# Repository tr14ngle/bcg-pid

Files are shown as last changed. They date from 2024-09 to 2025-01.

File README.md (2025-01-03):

# Digitally tuned analog PID controller for BCG system

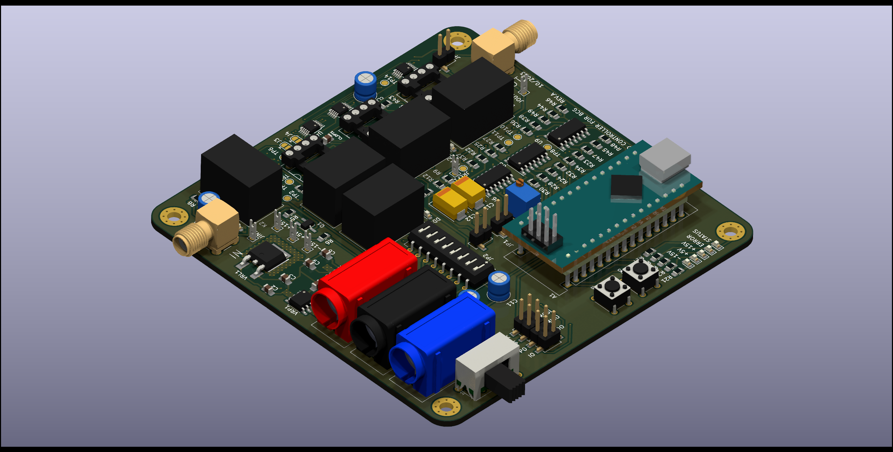
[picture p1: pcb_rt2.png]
PID Controller


## Overview

This repository contains KiCad files, as well as some LTSpice simulations for an experimental digitally tuned PID controller. The controller is designed to be part of a ballistocardiography (BCG) measuring system. In BCG, the function of the heart is measured by th forces caused by movement of the blood as a result of heartbeat. This is in contrast to better known electrocardiography (ECG), where heart function is assessed by measuring electrical signals. Compared to ECG, where the shape of the waveform is more important, in BCG the amplitude of the BCG signal carries important information about the heart's condition. Because BCG measures physical force, the patient's mass, among other things, can influence the amplitude of the signal. This makes long-term measurements difficult because the patient's weight and other affecting factors often vary over time. 

This PID controller is a continuation of a project completed Aalto University's Automation and Electrical Engineering Master Programme's Project Work course ([link to project folder](https://wiki.aalto.fi/display/AEEproject/Instrumentation+for+Ballistocardiography+2023?searchId=NLV66OIGJ)). Over the course, a system was implemented where the patient lays on suspended frame. The motion of the suspended frame can be controlled using two solenoids. A load cell is used to measure the position of the frame and a PID controller then controls the solenoids in such a way that the bed frame is kept stationary. This way, when the patient lays motionless, the BCG signal can be aquired from the control signals of the solenoids. This approach keeps the patient's body stationary, effectively canceling body inertia, which normalizes the resultant BCG signal. During the course, an unconventional, analogic PID controller was implemented. The controller was manually tuned using potentiometer which proved unfeasible, as manual tuning was quite diffictult and necessary for each measurement. This project attempts to address this by implementing digital tuning of the P, I and D blocks using digital potentiometers.

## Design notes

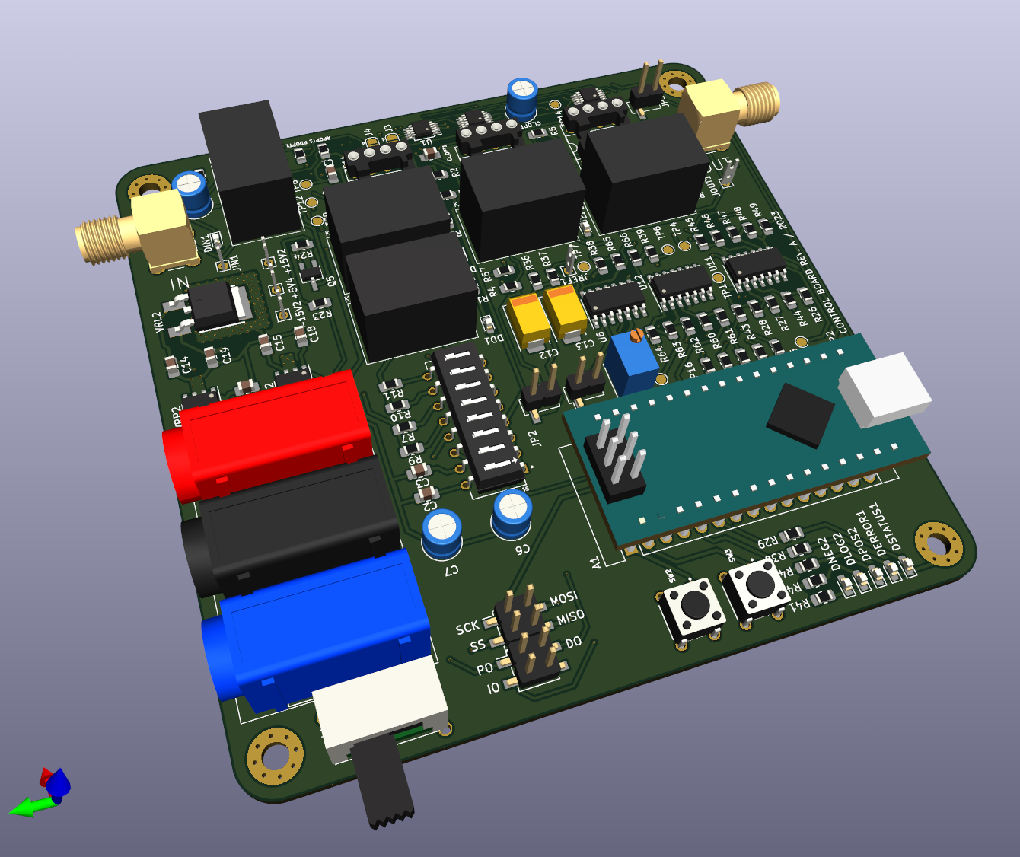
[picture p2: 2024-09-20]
pcb3.png

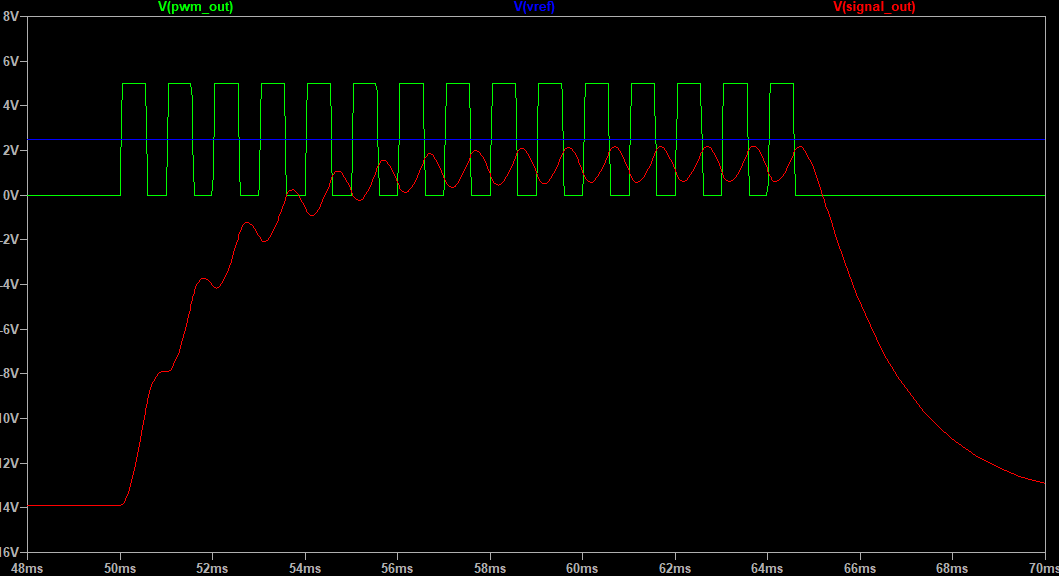
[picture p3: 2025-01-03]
bcg_spice/out_signals.PNG

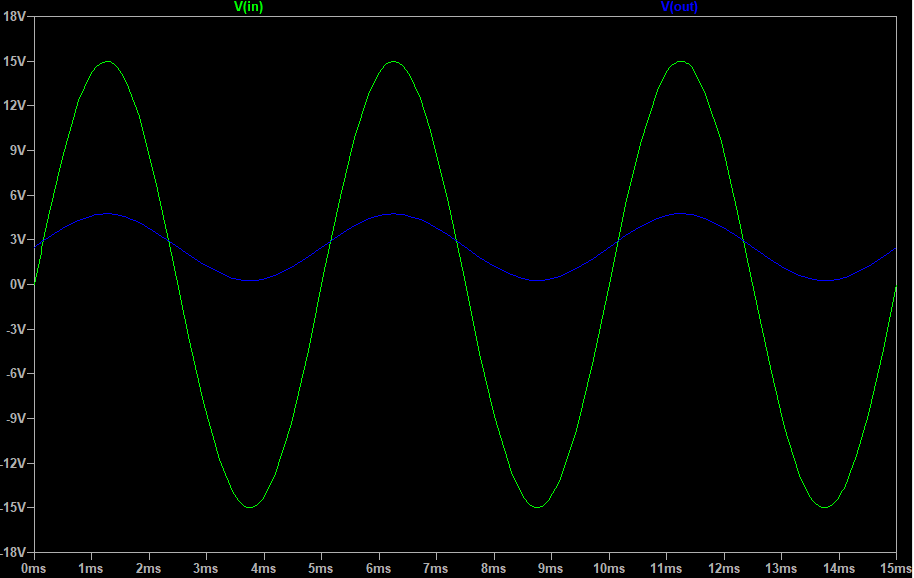
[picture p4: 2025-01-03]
bcg_spice/in_signals.PNG

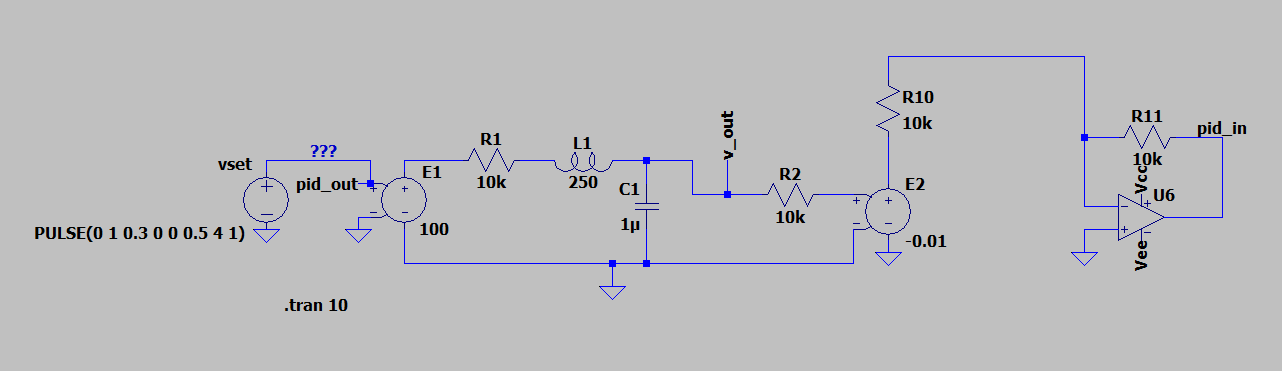
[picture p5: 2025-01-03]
bcg_spice/pid_dynamics.PNG

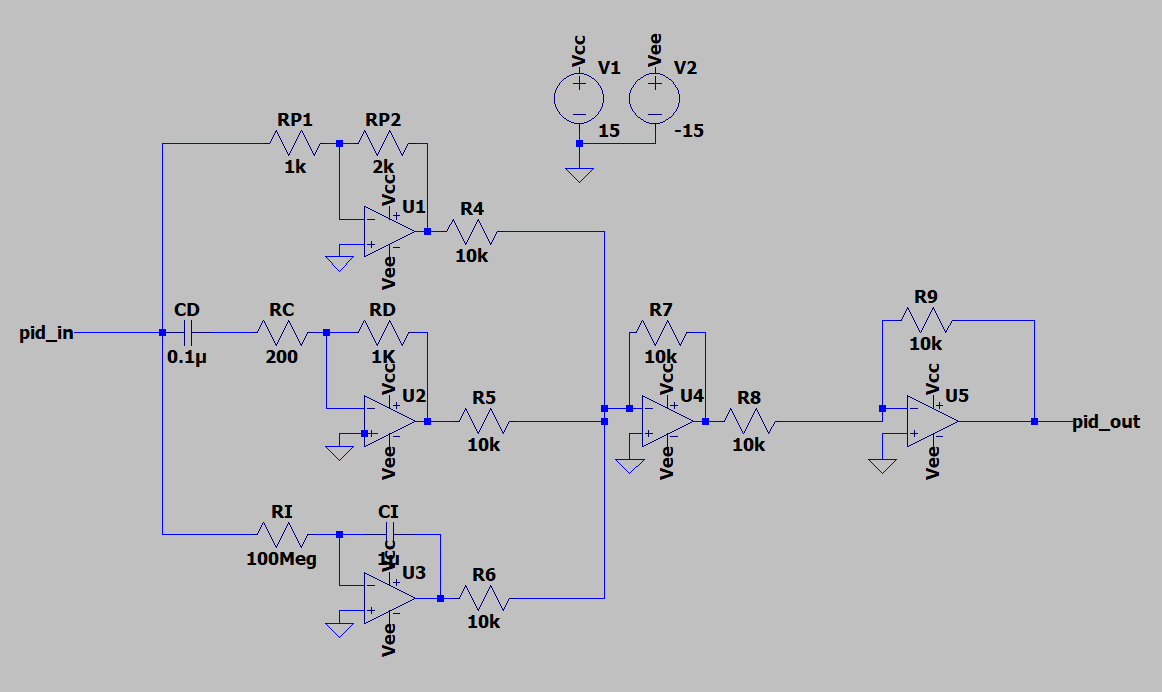
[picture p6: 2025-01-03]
bcg_spice/pid.png

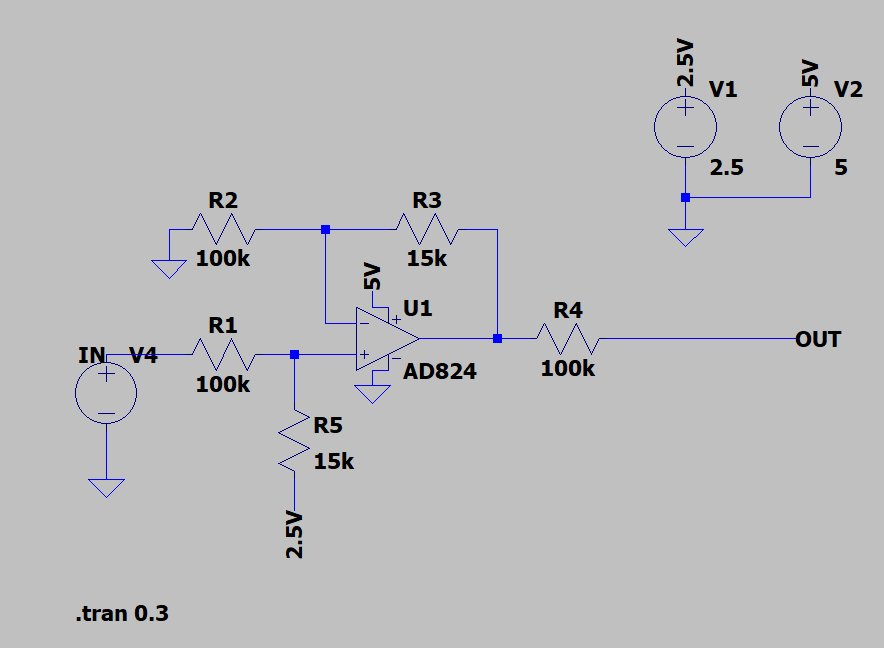
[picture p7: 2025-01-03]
bcg_spice/input_shifter.PNG

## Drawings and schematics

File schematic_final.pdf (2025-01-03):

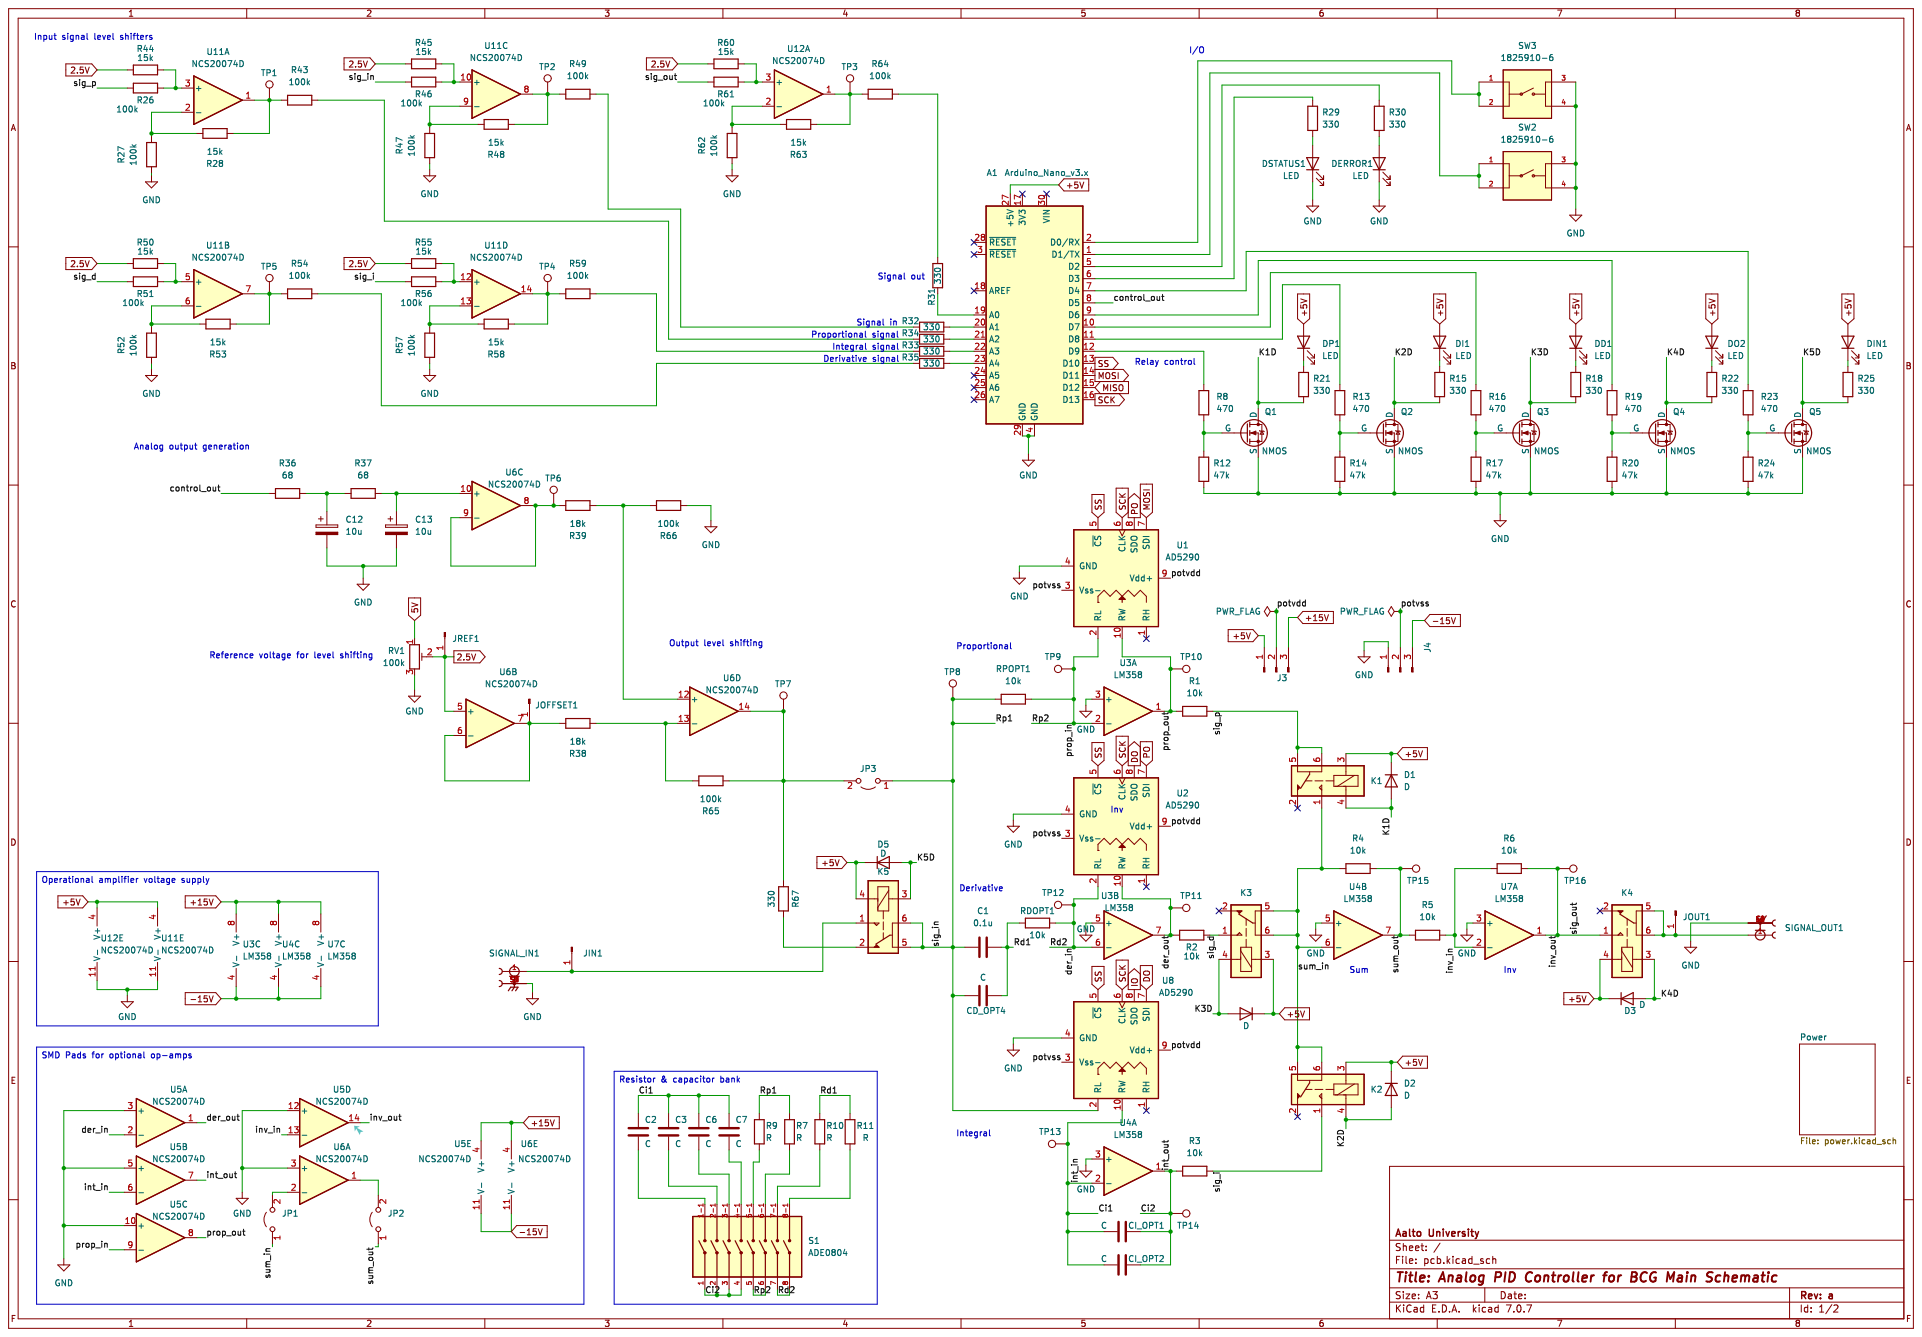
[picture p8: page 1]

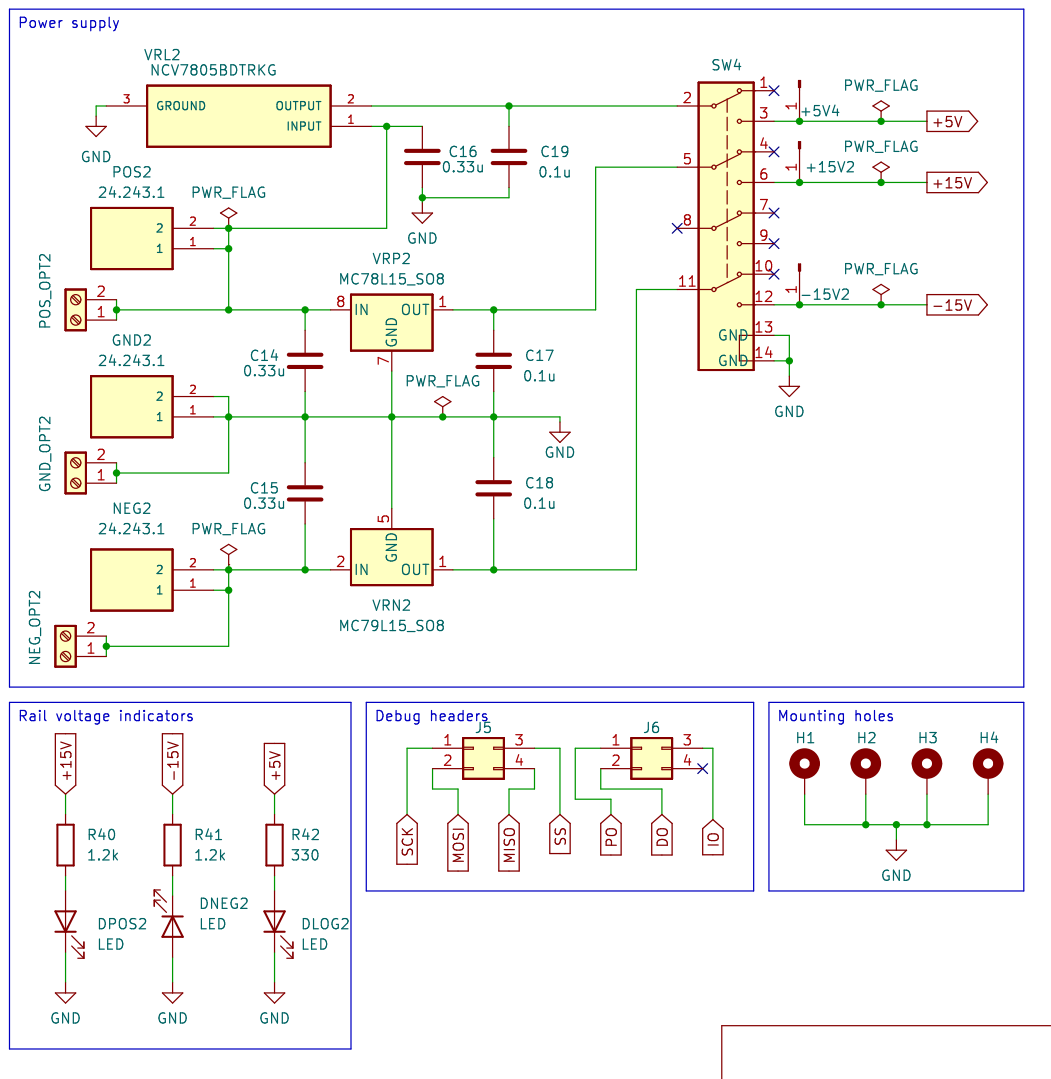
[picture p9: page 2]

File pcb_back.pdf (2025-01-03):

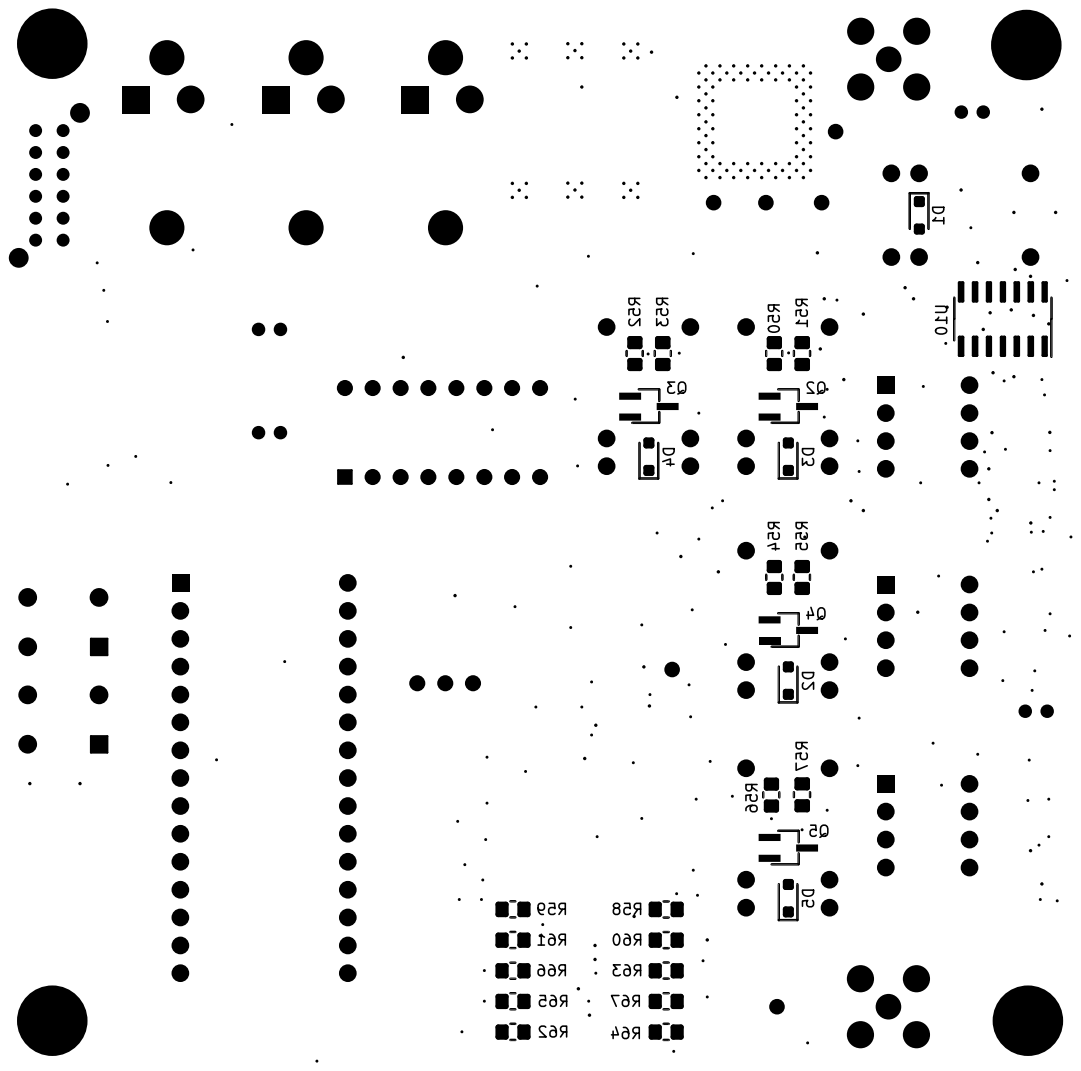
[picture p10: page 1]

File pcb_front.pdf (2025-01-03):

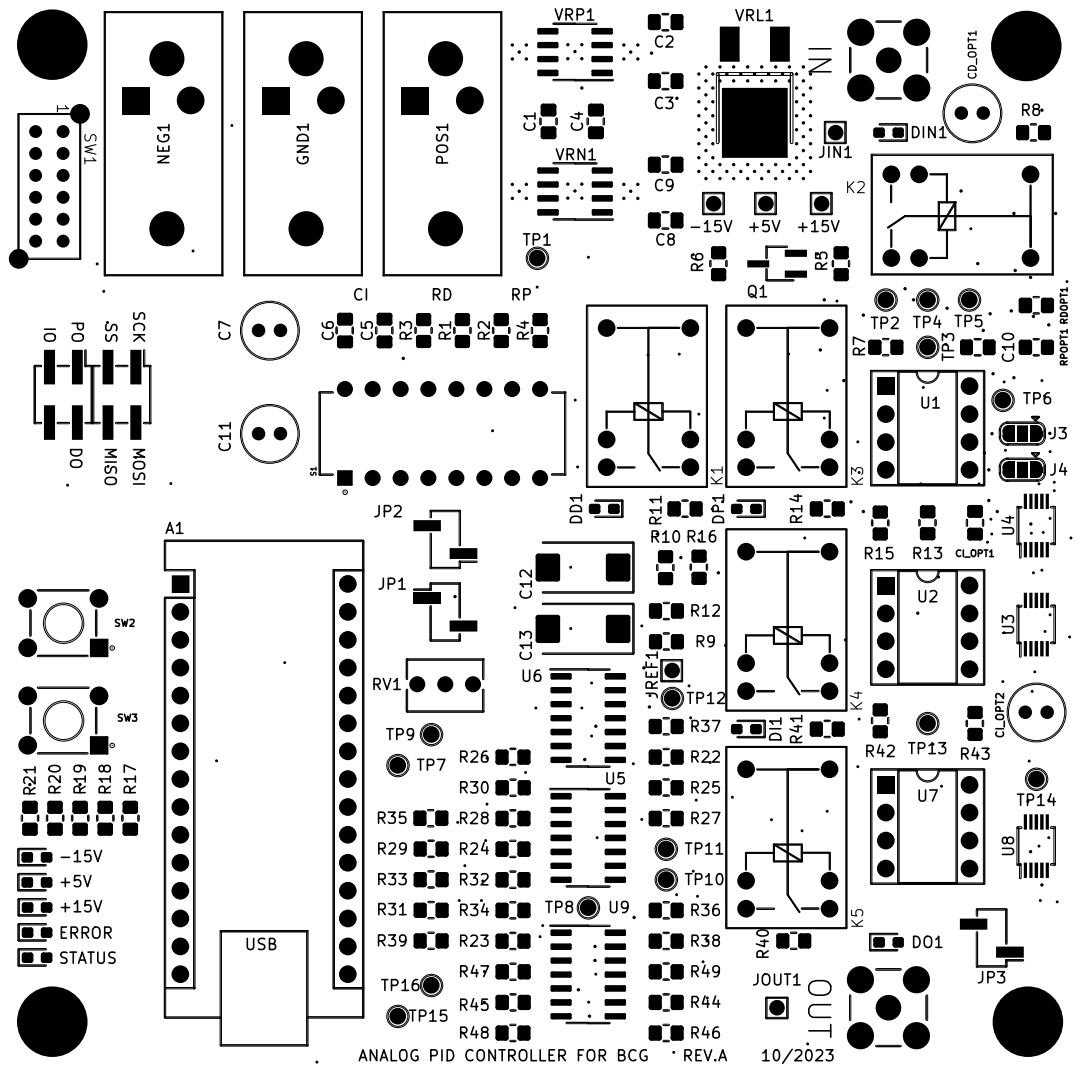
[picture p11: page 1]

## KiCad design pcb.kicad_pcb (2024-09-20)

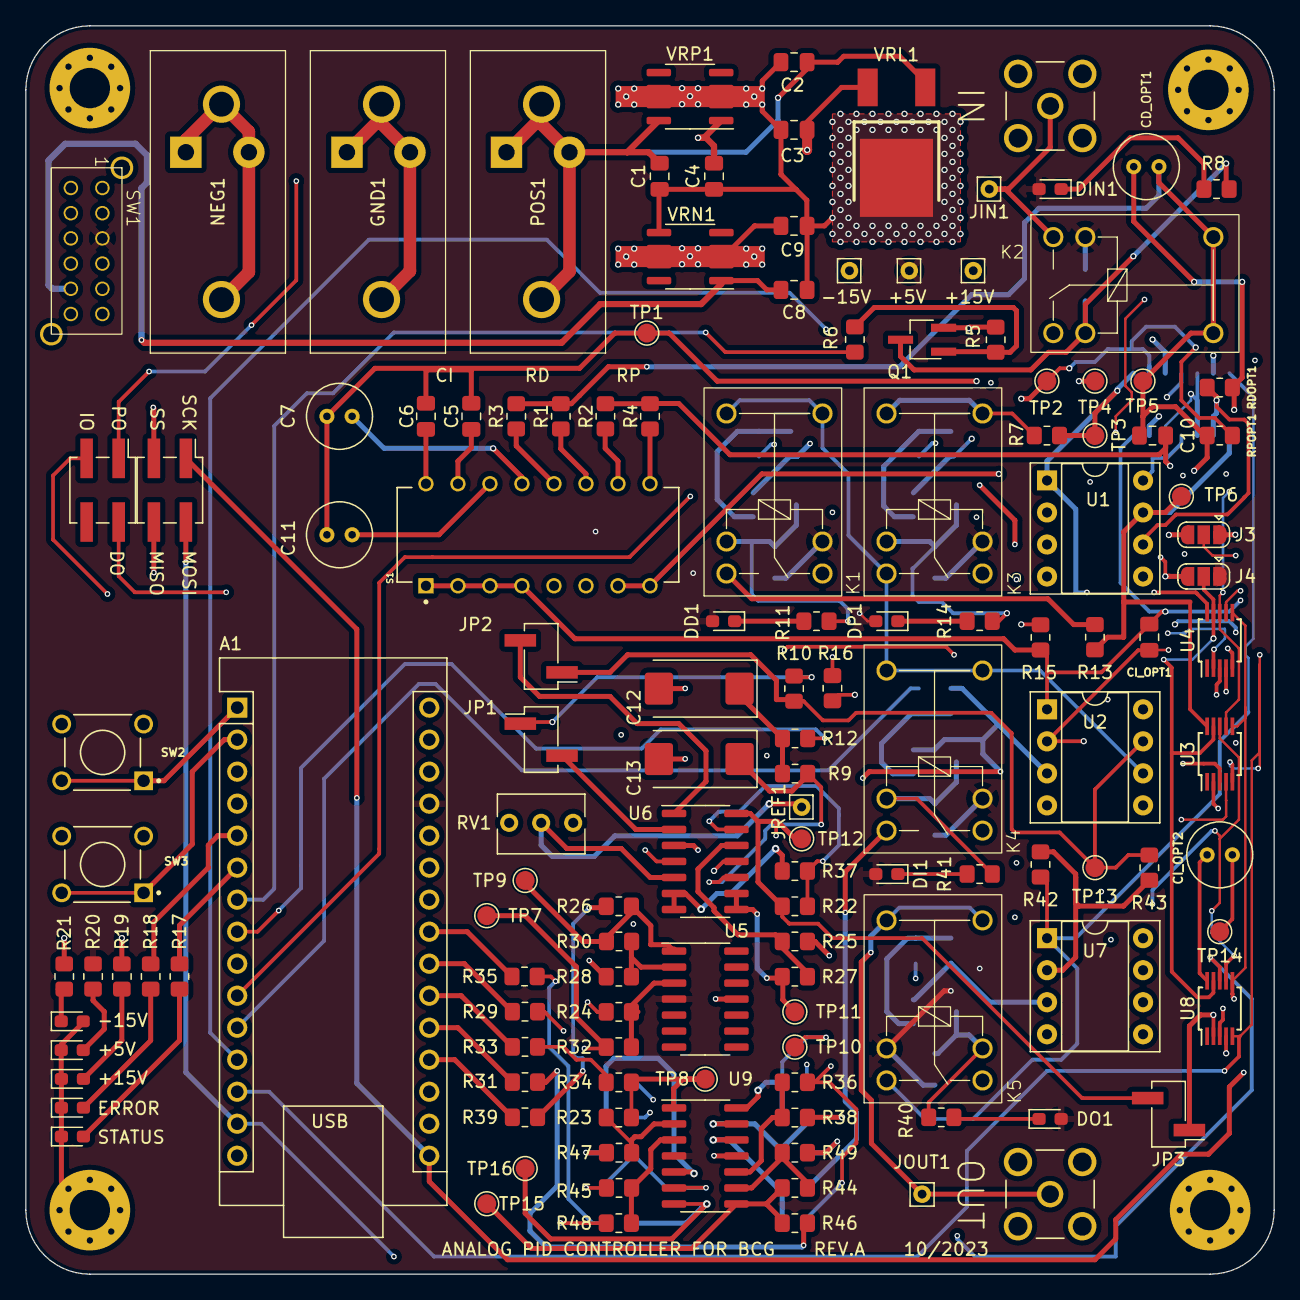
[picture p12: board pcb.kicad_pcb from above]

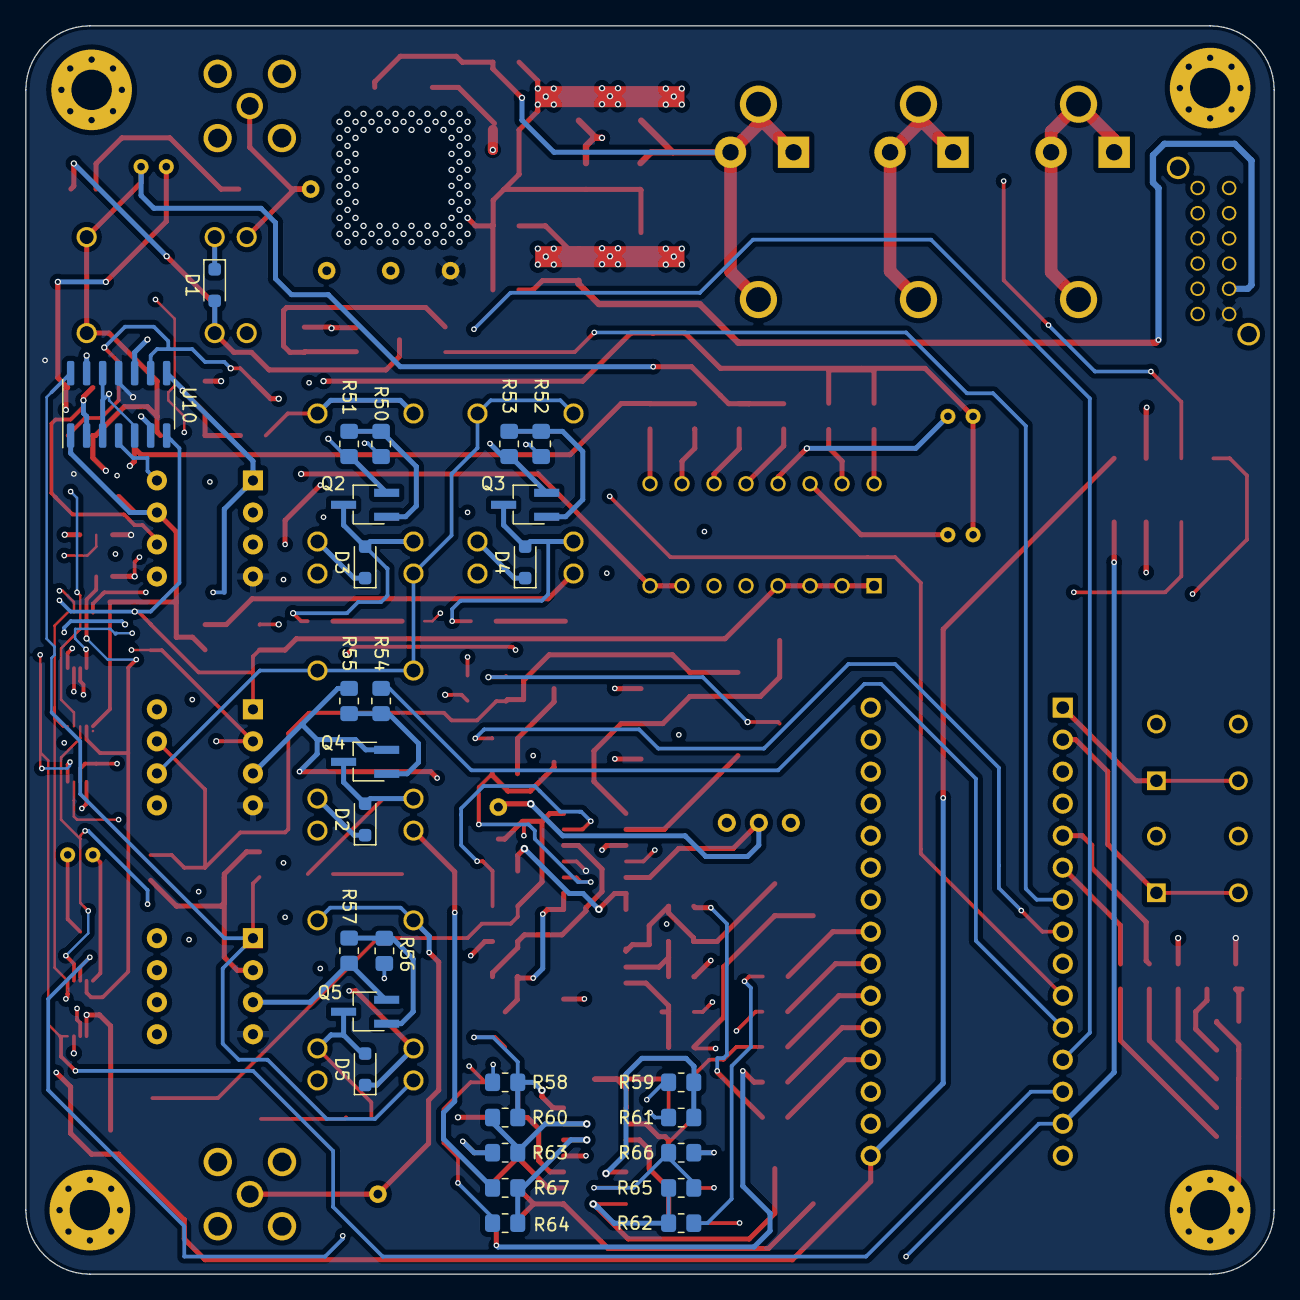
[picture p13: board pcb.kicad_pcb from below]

Board: 4 copper layers, 99.1 x 99.1 mm, 170 parts (28 on the bottom side), 109 nets.

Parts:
+1, +2: Conn_01x01_Pin; Pin_D0.7mm_L6.5mm_W1.8mm_FlatFork
-1: Conn_01x01_Pin; Pin_D0.7mm_L6.5mm_W1.8mm_FlatFork
A1: Arduino_Nano_v3.x; Arduino_Nano
C1, C2, C9: 0.33u; C_0805_2012Metric_Pad1.18x1.45mm_HandSolder
C3, C4, C8, C10: 0.1u; C_0805_2012Metric_Pad1.18x1.45mm_HandSolder
C5, C6: C; C_0805_2012Metric_Pad1.18x1.45mm_HandSolder
C7, C11: C; C_Radial_D5.0mm_H5.0mm_P2.00mm
C12, C13: 10u; CP_EIA-7343-40_Kemet-Y_Pad2.25x2.55mm_HandSolder
CD_OPT1: C; C_Radial_D5.0mm_H5.0mm_P2.00mm
CI_OPT1: C; C_0805_2012Metric_Pad1.18x1.45mm_HandSolder
CI_OPT2: C; C_Radial_D5.0mm_H5.0mm_P2.00mm
D1, D2, D3, D4, D5: D; D_SOD-323_HandSoldering
DD1: LED; LED_0603_1608Metric_Pad1.05x0.95mm_HandSolder
DERROR1: LED; LED_0603_1608Metric_Pad1.05x0.95mm_HandSolder
DI1: LED; LED_0603_1608Metric_Pad1.05x0.95mm_HandSolder
DIN1: LED; LED_0603_1608Metric_Pad1.05x0.95mm_HandSolder
DLOG1: LED; LED_0603_1608Metric_Pad1.05x0.95mm_HandSolder
DNEG1: LED; LED_0603_1608Metric_Pad1.05x0.95mm_HandSolder
DO1: LED; LED_0603_1608Metric_Pad1.05x0.95mm_HandSolder
DP1: LED; LED_0603_1608Metric_Pad1.05x0.95mm_HandSolder
DPOS1: LED; LED_0603_1608Metric_Pad1.05x0.95mm_HandSolder
DSTATUS1: LED; LED_0603_1608Metric_Pad1.05x0.95mm_HandSolder
GND1: 24.243.1; 242431
GND_OPT1: Screw_Terminal_01x02; TerminalBlock_RND_205-00276_1x02_P5.00mm_Vertical
H1, H2, H3, H4: MountingHole_Pad; MountingHole_3.2mm_M3_Pad_Via
IN: CONSMA002; LINX_CONSMA002
J1, J2: Conn_02x02_Top_Bottom; PinHeader_2x02_P2.54mm_Vertical_SMD
J3, J4: Conn_01x03_Pin; SolderJumper-3_P1.3mm_Open_RoundedPad1.0x1.5mm
JIN1: Conn_01x01_Pin; Pin_D0.7mm_L6.5mm_W1.8mm_FlatFork
JOUT1: Conn_01x01_Pin; Pin_D0.7mm_L6.5mm_W1.8mm_FlatFork
JP1, JP2, JP3: Jumper_2_Open; PinHeader_1x02_P2.54mm_Vertical_SMD_Pin1Left
JREF1: Conn_01x01_Pin; Pin_D0.7mm_L6.5mm_W1.8mm_FlatFork
K1, K2, K3, K4, K5: SRS-3V
NEG1: 24.243.1; 242431
NEG_OPT1: Screw_Terminal_01x02; TerminalBlock_RND_205-00276_1x02_P5.00mm_Vertical
OUT: CONSMA002; LINX_CONSMA002
POS1: 24.243.1; 242431
POS_OPT1: Screw_Terminal_01x02; TerminalBlock_RND_205-00276_1x02_P5.00mm_Vertical
Q1, Q2, Q3, Q4, Q5: NMOS; TSOT-23_HandSoldering
R1, R2, R3, R4: R; R_0805_2012Metric_Pad1.20x1.40mm_HandSolder
R5, R51, R53, R55, R57: 47k; R_0805_2012Metric_Pad1.20x1.40mm_HandSolder
R6, R50, R52, R54, R56: 470; R_0805_2012Metric_Pad1.20x1.40mm_HandSolder
R7, R10, R13, R15, R42, R43: 10k; R_0805_2012Metric_Pad1.20x1.40mm_HandSolder
R8, R11, R14, R16, R17, R18, R20, R29, R31, R33, R35, R39, R40, R41: 330; R_0805_2012Metric_Pad1.20x1.40mm_HandSolder
R9, R12: 68; R_0805_2012Metric_Pad1.20x1.40mm_HandSolder
R19, R21: 1.2k; R_0805_2012Metric_Pad1.20x1.40mm_HandSolder
R22, R25, R26, R28, R32, R34, R38, R46, R47, R48, R49, R58, R61, R62, R63, R66, R67: 100k; R_0805_2012Metric_Pad1.20x1.40mm_HandSolder
R23, R24, R30, R36, R44, R45, R59, R60, R64, R65: 15k; R_0805_2012Metric_Pad1.20x1.40mm_HandSolder
R27, R37: 18k; R_0805_2012Metric_Pad1.20x1.40mm_HandSolder
RDOPT1: 10k; R_0805_2012Metric_Pad1.20x1.40mm_HandSolder
RPOPT1: 10k; R_0805_2012Metric_Pad1.20x1.40mm_HandSolder
RV1: 100k; Potentiometer_Bourns_3266Y_Vertical
S1: ADE0804; SW_ADE0804
SW1: EG4208
SW2, SW3: 1825910-6; SW_1825910-6-4
TP1, TP2, TP3, TP4, TP5, TP6, TP7, TP8, TP9, TP10, TP11, TP12, TP13, TP14, TP15, TP16: TestPoint; TestPoint_Pad_D1.5mm
U1, U2, U7: LM358; DIP-8_W7.62mm_Socket
U3, U4, U8: AD5290; MSOP-10_3x3mm_P0.5mm
U5, U6, U9, U10: NCS20074D; SOIC-14_3.9x8.7mm_P1.27mm
VRL1: NCV7805BDTRKG; NCV7805BDTRKG_1
VRN1: MC79L15_SO8; SOIC-8_3.9x4.9mm_P1.27mm
VRP1: MC78L15_SO8; SOIC-8_3.9x4.9mm_P1.27mm

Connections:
2.5V: JREF1.1, R24.1, R36.1, R45.1, R59.1, R64.1, RV1.2, U6.5 (+)
+5V: +2.1, A1.27 (+5V), D1.1 (K), D2.1 (K), D3.1 (K), D4.1 (K), D5.1 (K), DD1.2 (A), DI1.2 (A), DIN1.2 (A), DO1.2 (A), DP1.2 (A), J4.1, K1.3, K2.4, K3.3, K4.3, K5.4, R20.2, SW1.3, U5.4 (V+), U9.4 (V+)
+15V: +1.1, J4.3, R19.2, SW1.6, U1.8 (V+), U2.8 (V+), U6.4 (V+), U7.8 (V+), U10.4 (V+)
-15V: -1.1, J3.3, R21.2, SW1.12, U1.4 (V-), U2.4 (V-), U6.11 (V-), U7.4 (V-), U10.11 (V-)
/Ci1: C5.1, C6.1, C7.1, C11.1, CI_OPT1.1, CI_OPT2.1, TP1.1, U2.2 (-), U8.10 (RW), U10.6 (-)
/Ci2: CI_OPT1.2, CI_OPT2.2, R15.1, S1.1, S1.2, S1.3, S1.4, TP14.1, U2.1, U10.7
/K1D: D3.2 (A), K3.4, Q2.1 (D), R14.1
/K2D: D2.2 (A), K4.4, Q4.1 (D), R41.1
/K3D: D4.2 (A), K1.4, Q3.1 (D), R11.1
/K4D: D5.2 (A), K5.3, Q5.1 (D), R40.1
/K5D: D1.2 (A), K2.3, Q1.1 (D), R8.1
/Rd1: C10.2, CD_OPT1.2, R2.2, R4.2, RDOPT1.1
/Rd2: RDOPT1.2, S1.7, S1.8, TP4.1, U1.6 (-), U3.2 (RL), U10.2 (-)
/Rp1: C10.1, CD_OPT1.1, JP3.1 (A), K2.5, K2.6, R1.2, R3.2, R38.1, RPOPT1.1, TP5.1, U8.2 (RL)
/Rp2: RPOPT1.2, S1.5, S1.6, TP2.1, U1.2 (-), U4.2 (RL), U10.9 (-)
/control_out: A1.8 (D5), R12.2
/der_out: R13.1, TP6.1, U1.7, U3.10 (RW), U10.1
/inv_in: R42.1, R43.2, U7.2 (-), U10.13 (-)
/inv_out: K5.1, R32.1, R42.2, TP7.1, U7.1, U10.14
/potvdd: J4.2, U3.9 (Vdd+), U4.9 (Vdd+), U8.9 (Vdd+)
/potvss: J3.2, U3.3 (Vss-), U4.3 (Vss-), U8.3 (Vss-)
/prop_out: R7.1, TP3.1, U1.1, U4.10 (RW), U10.8
/sig_d: K1.1, R13.2, R61.1
/sig_i: K4.1, R15.2, R67.1
/sig_p: K3.5, K3.6, R7.2, R48.1
/sum_in: JP1.1 (A), K1.5, K1.6, K3.1, K4.5, K4.6, R10.1, U2.6 (-)
/sum_out: JP2.1 (A), R10.2, R43.1, TP13.1, U2.7
DO: J2.2, U3.8 (SDO), U8.7 (SDI)
GND: A1.4 (GND), A1.29 (GND), C1.1, C2.1, C3.1, C4.1, C8.2, C9.2, C12.2, C13.2, DERROR1.1 (K), DLOG1.1 (K), DNEG1.2 (A), DPOS1.1 (K), DSTATUS1.1 (K), GND1.1, GND1.2, GND_OPT1.1, GND_OPT1.2, H1.1, H2.1, H3.1, H4.1, IN.S1, IN.S2, IN.S3, IN.S4, J3.1, OUT.S1, OUT.S2, OUT.S3, OUT.S4, Q1.3 (S), Q2.3 (S), Q3.3 (S), Q4.3 (S), Q5.3 (S), R5.1, R25.1, R28.1, R47.1, R49.1, R51.1, R53.1, R55.1, R57.1, R63.1, R66.1, RV1.3, SW1.13 (GND), SW1.14 (GND), SW2.3, SW2.4, SW3.3, SW3.4, U1.3 (+), U1.5 (+), U2.3 (+), U2.5 (+), U3.4 (GND), U4.4 (GND), U5.11 (V-), U6.3 (+), U7.3 (+), U8.4 (GND), U9.11 (V-), U10.3 (+), U10.5 (+), U10.10 (+), U10.12 (+), VRL1.3 (GROUND), VRN1.5 (GND), VRP1.2 (GND), VRP1.3 (GND), VRP1.6 (GND), VRP1.7 (GND)
IO: J2.3, U8.8 (SDO)
MISO: A1.15 (D12), J1.4
MOSI: A1.14 (D11), J1.2, U4.7 (SDI)
unnamed: A1.19 (A0), R39.1
unnamed: A1.20 (A1), R31.2
unnamed: A1.21 (A2), R33.2
unnamed: A1.22 (A3), R29.2
unnamed: A1.23 (A4), R35.2
unnamed: A1.2 (D0/RX), SW3.1, SW3.2
unnamed: A1.1 (D1/TX), SW2.1, SW2.2
unnamed: A1.5 (D2), R18.2
unnamed: A1.6 (D3), R17.2
unnamed: A1.7 (D4), R6.2
unnamed: A1.9 (D6), R56.2
unnamed: A1.10 (D7), R52.2
unnamed: A1.11 (D8), R54.2
unnamed: A1.12 (D9), R50.2
unnamed: C6.2, S1.1-1
unnamed: C5.2, S1.2-1
unnamed: C11.2, S1.3-1
unnamed: C7.2, S1.4-1
unnamed: C12.1, R9.2, R12.1
unnamed: DD1.1 (K), R11.2
unnamed: DERROR1.2 (A), R18.1
unnamed: DI1.1 (K), R41.2
unnamed: DIN1.1 (K), R8.2
unnamed: DLOG1.2 (A), R20.1
unnamed: DNEG1.1 (K), R21.1
unnamed: DO1.1 (K), R40.2
unnamed: DP1.1 (K), R14.2
unnamed: DPOS1.2 (A), R19.1
unnamed: DSTATUS1.2 (A), R17.1
unnamed: IN.1, JIN1.1, K2.1
unnamed: R37.2, U6.6 (-), U6.7
unnamed: JOUT1.1, K5.5, K5.6, OUT.1
unnamed: JP1.2 (B), U6.2 (-)
unnamed: JP2.2 (B), U6.1
unnamed: JP3.2 (B), R16.1, R22.1, TP12.1, U6.14
unnamed: K2.2, R16.2
unnamed: C9.1, NEG1.1, NEG1.2, NEG_OPT1.1, NEG_OPT1.2, VRN1.2 (IN), VRN1.3 (IN), VRN1.6 (IN), VRN1.7 (IN)
unnamed: C1.2, C2.2, POS1.1, POS1.2, POS_OPT1.1, POS_OPT1.2, VRL1.1 (INPUT), VRP1.8 (IN)
unnamed: Q2.2 (G), R50.1, R51.2
unnamed: Q4.2 (G), R54.1, R55.2
unnamed: Q3.2 (G), R52.1, R53.2
unnamed: Q5.2 (G), R56.1, R57.2
unnamed: Q1.2 (G), R5.2, R6.1
unnamed: R1.1, S1.6-1
unnamed: R3.1, S1.5-1
unnamed: R2.1, S1.7-1
unnamed: R4.1, S1.8-1
unnamed: R23.1, R34.1, TP8.1, U9.1
unnamed: R26.2, R39.2
unnamed: R31.1, R46.2
unnamed: R33.1, R34.2
unnamed: R29.1, R58.2
unnamed: R35.1, R62.2
unnamed: R44.1, R46.1, TP15.1, U9.8
unnamed: R62.1, R65.1, TP16.1, U9.7
unnamed: R58.1, R60.1, TP10.1, U9.14
unnamed: R26.1, R30.1, TP9.1, U5.1
unnamed: C13.1, R9.1, U6.10 (+)
unnamed: R27.2, TP11.1, U6.8, U6.9 (-)
unnamed: R25.2, R27.1, U6.12 (+)
unnamed: R22.2, R37.1, U6.13 (-)
unnamed: R45.2, R48.2, U9.3 (+)
unnamed: R23.2, R47.2, U9.2 (-)
unnamed: R59.2, R61.2, U9.5 (+)
unnamed: R65.2, R66.2, U9.6 (-)
unnamed: R36.2, R38.2, U9.10 (+)
unnamed: R44.2, R49.2, U9.9 (-)
unnamed: R64.2, R67.2, U9.12 (+)
unnamed: R60.2, R63.2, U9.13 (-)
unnamed: R24.2, R32.2, U5.3 (+)
unnamed: R28.2, R30.2, U5.2 (-)
unnamed: C3.2, SW1.2, VRL1.2 (OUTPUT)
unnamed: C8.1, SW1.11, VRN1.1 (OUT)
unnamed: C4.2, SW1.5, VRP1.1 (OUT)
PO: J2.1, U3.7 (SDI), U4.8 (SDO)
SCK: A1.16 (D13), J1.1, U3.6 (CLK), U4.6 (CLK), U8.6 (CLK)
SS: A1.13 (D10), J1.3, U3.5 (~CS), U4.5 (~CS), U8.5 (~CS)
